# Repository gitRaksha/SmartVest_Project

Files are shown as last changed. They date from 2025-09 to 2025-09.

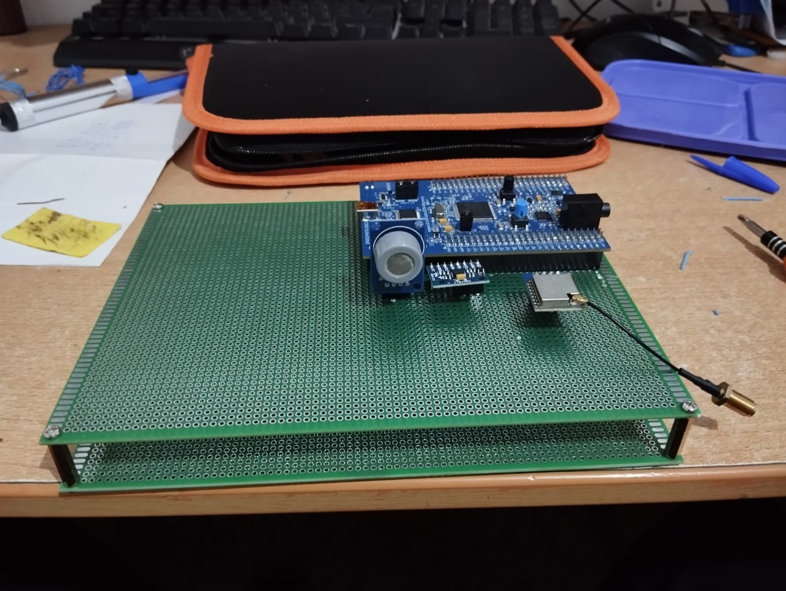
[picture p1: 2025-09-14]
Images/WhatsApp Image 2025-05-27 à 20.13.04_19ec891d.jpg

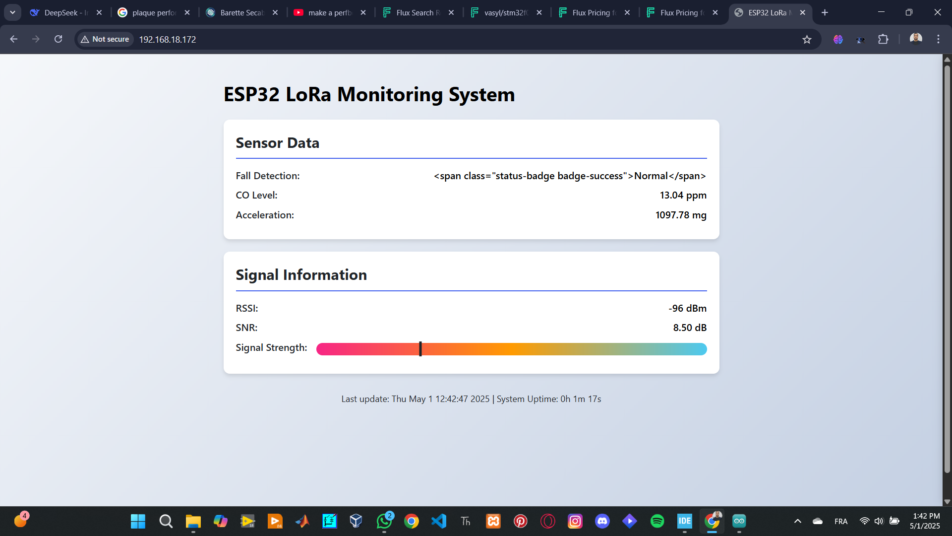
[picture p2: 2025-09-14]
Images/Capture d'écran 2025-05-01 134303.png

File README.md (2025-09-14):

       

# 🦺 Smart Safety Vest – IoT Project  

A **Smart Safety Vest** designed for workers in hazardous environments.  
It detects **toxic gas (CO)** and **falls**, then transmits alerts via **LoRa (SX1278)** from an **STM32F407G** to an **ESP32**, which hosts a **web dashboard** for monitoring.  

This project was developed as an **End-of-Year Engineering Project (PFA)**.  

---

## ✨ Features
- 📡 **LoRa Communication**: Long-range wireless transmission of alerts.  
- 🧭 **Fall Detection**: Using MPU6050 accelerometer.  
- 🌫 **Gas Detection**: CO levels via MQ-7 sensor.  
- 🌍 **Web Dashboard**: ESP32 receives LoRa data and displays it on a local web page.  
- 🔋 **Portable Design**: PCB + 3D printed case for deployment.  

---

## 🛠 Hardware Used
🔹 **STM32F407G** microcontroller (main vest controller)  
🔹 **ESP32** (LoRa receiver + Wi-Fi access point / web interface)  
🔹 **LoRa SX1278** transceiver modules (433 MHz)  
🔹 **MQ-7** gas sensor (CO detection)  
🔹 **MPU6050** accelerometer/gyroscope (fall detection)  
🔹 **Buzzer + LED indicators** (local alerts)  
🔹 **Li-Ion Battery 3.7V** + **TP4056 charger module**  
🔹 **Custom PCB** (Proteus/Altium design included)  
🔹 **3D Printed Enclosure** (OpenSCAD design provided)  

---

## 💻 Software & Tools
- 🖥️ **STM32CubeIDE** or **Keil uVision** (STM32 firmware)  
- 🖥️ **Arduino IDE** (ESP32 firmware)  
- 🖥️ **Proteus** / **Altium Designer** (PCB design)  
- 🖥️ **OpenSCAD** (3D case design)  
- 🖥️ **Node-RED (optional)** (IoT dashboards)  

---

## 📂 Project Structure

```text
.
├── 3D design OpenScad # Enclosure design (box + lid)
├── CODE # Source codes
│ ├── esp32_final # ESP32 receiver + web server
│ └── stm32_final_code # STM32 sensor reading + LoRa sender
├── Images # Screenshots, wiring photos, etc.
├── PCB # PCB design files (Altium + Proteus)
├── Rapport_PFA.pdf # Final written report
└── Vidéo.mp4 # Demo video of the project

 ```

---

## 🚀 Deployment  

### 🔹 STM32 (Sender – on the vest)  
1. Open `stm32_final_code` in **STM32CubeIDE**.  
2. Flash the firmware to your STM32F407G.  
3. Connect MQ-7 + MPU6050 + LoRa SX1278 as per schematic.  

### 🔹 ESP32 (Receiver – Web Dashboard)  
1. Open `esp32_final` in **Arduino IDE**.  
2. Install required libraries:  
   - `LoRa.h`  
   - `WiFi.h`  
   - `WebServer.h`  
3. Flash to ESP32.  
4. Connect ESP32 to LoRa SX1278.  
5. Open a browser and navigate to the ESP32 IP to view alerts.  

---

## 📸 Images & Demo
Some project visuals are stored in the [Images](./Images) folder.  
A demo video is available: [Vidéo.mp4](./Vidéo.mp4).  

---

## 🔮 Future Improvements

🌍 Add GPS for geolocation

📡 Add GSM/4G for connectivity without LoRa

🔋 Optimize power management

☁️ Cloud-based dashboard (IoT integration)

---

## 📜 License
This project is licensed under the **MIT License** – see the [LICENSE](./LICENSE) file for details.  

---

## 👥 Authors
- **Marwen Mekni** 
- **Bensaid Mohamed**
- **Khemiri Haythem** 

---

⭐ If you like this project, feel free to fork, star, or reuse it for your own IoT projects!

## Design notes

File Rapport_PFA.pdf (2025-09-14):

## Étude et conception d’un Gilet Intelligent pour Travailleurs en Milieu Dangereux avec Intégration de l’IoT

BENSAID Mohamed, MEKNI Marwen, KHEMIRI Haythem Mohamedbensaidtn@gmail.com, mekni0845@gmail.com, haythemkhmiri92@gmail.com

(1) L'Ecole Supérieure d'Ingénieurs et des Etudes Technologiques ESIET -UAS :34, Rue Cyrus Legrand, Tunis, Tunisie.
(2) L'Ecole Supérieure d'Ingénieurs et des Etudes Technologiques ESIET -UAS :34, Rue Cyrus Legrand, Tunis, Tunisie.
RESUME : Ce projet présente la conception et la réalisation d’un gilet intelligent destiné à renforcer la sécurité des travailleurs évoluant dans des environnements dangereux. L’objectif principal est de détecter les chutes et les gaz toxiques, notamment le monoxyde de carbone, le méthane et l’hydrogène, afin de déclencher des alertes en temps réel.
Le système est basé sur un microcontrôleur STM32F407G, relié à deux capteurs principaux : le MPU6050 pour la détection des chutes, et le capteur MQ-7 pour la surveillance des gaz. Les données collectées sont transmises via un module LoRa SX1278 vers un ESP32, qui les affiche sur une interface web hébergée localement.
L'ensemble du système fonctionne de manière autonome et sans réseau externe, ce qui le rend particulièrement adapté aux zones industrielles isolées. Le projet a été développé en suivant une approche modulaire, avec des tests individuels pour chaque composant, puis une intégration finale réussie. Il constitue une base solide pour des applications de sécurité connectée dans le domaine professionnel.
Mots-clés : Capteurs, Internet des Objets (IoT), Pédagogique, Sécurité au travail, Détection de chute, Capteur de gaz (MQ-7), STM32F407G, LoRa SX1278, ESP32, Interface web embarquée.

### 1. INTRODUCTION

Dans les environnements industriels et les chantiers à haut risque, la sécurité des travailleurs est une priorité absolue. Chaque année, des millions d'accidents surviennent, souvent causés par des chutes ou l’exposition à des gaz toxiques tels que le monoxyde de carbone (CO), le méthane (CH₄) ou l’hydrogène (H₂). Malgré les efforts en matière de prévention, ces dangers persistent, en particulier dans les zones peu surveillées. Face à ce constat, les objets connectés (IoT) offrent de nouvelles perspectives pour améliorer la sécurité en temps réel. Ce projet s'inscrit dans cette démarche, avec la conception d’un gilet intelligent capable de détecter les chutes et de surveiller la qualité de l’air, tout en transmettant les informations sans fil à une plateforme distante.
Le gilet se veut léger, autonome et adapté aux contraintes du terrain, intégrant des capteurs précis et une technologie de transmission à longue portée. Il vise à renforcer la protection des travailleurs en permettant une réaction rapide en cas d’anomalie détectée. Ce prototype démontre comment des solutions embarquées peuvent être mises au service de la sécurité dans des milieux exigeants.

### 2. CONCEPTION MECANIQUE

Pour la partie mécanique du projet, nous avons conçu un boîtier sur mesure à l’aide du logiciel OpenSCAD. Ce boîtier a été généré entièrement par code, ce qui a permis une modélisation paramétrique précise adaptée aux dimensions réelles des composants électroniques, notamment la carte

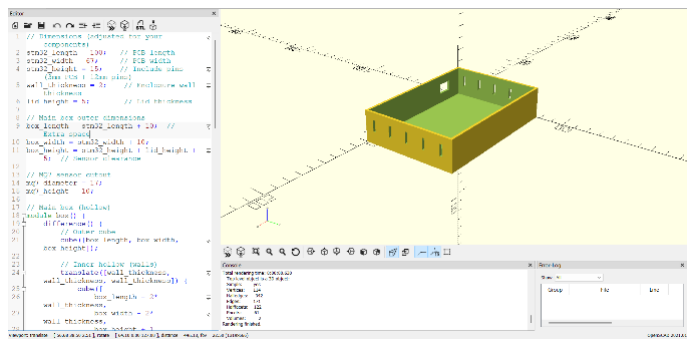
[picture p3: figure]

STM32F407G, le capteur MQ-7 et le module LoRa.

La structure comprend des parois d’épaisseur uniforme, un système de couvercle emboîtable, ainsi que des ouvertures dédiées pour le port USB, le capteur de gaz, l’antenne LoRa et la ventilation. Des fentes d’aération ont été ajoutées sur les côtés afin d’assurer une meilleure circulation de l’air à l’intérieur du boîtier.
Cette approche a permis une intégration compacte,
propre | et | fonctionnelle | de | l’ensemble | des
composants tout en assurant une certaine protection physique lors des tests. Le modèle final a été exporté en STL pour impression 3D si nécessaire.

Figure 1 : Conception 3D de boîtier

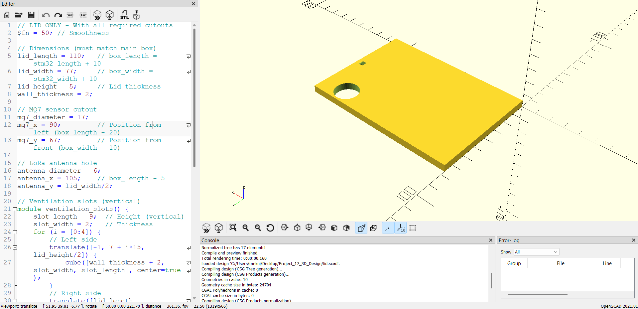
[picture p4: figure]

Figure 2 : Conception 3D du couvercle emboîtable

- Câblage électrique

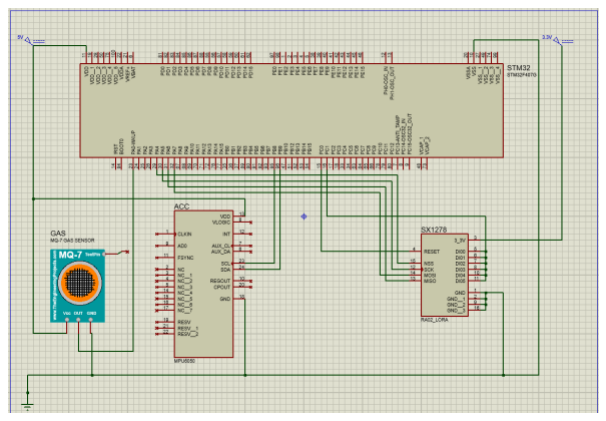
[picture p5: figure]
Figure 2 : Capteur de couleur TCS2300
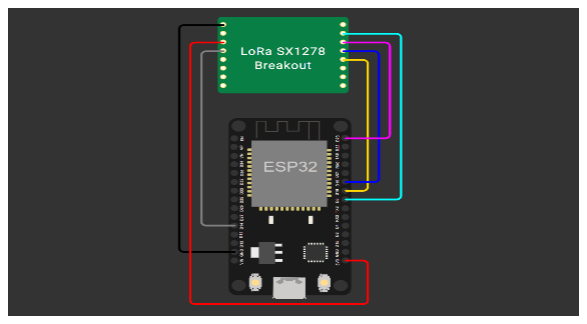
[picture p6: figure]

Figure 4 : Schéma électrique avec Proteus 8 de STM32 et ses capteurs

Le tableau suivant présente les connexions entre les broches des microcontrôleurs (STM32F407G et ESP32) et les différents modules utilisés dans le projet.

MPU6050 / STM32 | STM32/LORA | LORA/ESP32
VCC | 5V | VCC | 3, 3V | 3, 3V | 3, 3V
GND | GND | GND | GND | GND | GND
SDA | PB8 | PC0 | RST | RST | 19
SCL | PB9 | PC1 | DIO0 | DIO0 | 27
MQ7 /STM32 | | PA4 | NSS | NSS | 26
VCC | 5V | PA5 | SCK | SCK | 5
GND | GND | PA6 | MISO | MISO | 14
AO | PA0 | PA7 | MOSI | MOSI | 18

Tableau 1 : Table des connexions (Pinout)

### 3. ARCHITECTURE FONCTIONNEL

DU SYSTEME

Le projet ne comporte pas de parties mécaniques mobiles, donc aucun schéma cinématique n’est requis.
À la place, nous présentons ici l'architecture fonctionnelle du système qui repose sur un microcontrôleur STM32F407G connecté à deux capteurs : le MPU6050 en I2C pour détecter les chutes, et le MQ-7 en entrée analogique pour mesurer les gaz. Les données sont envoyées via le module LoRa SX1278 (SPI) à une carte ESP32, qui les affiche sur une interface web locale. Le schéma ci-dessous montre les connexions et le flux d’information entre les composants.

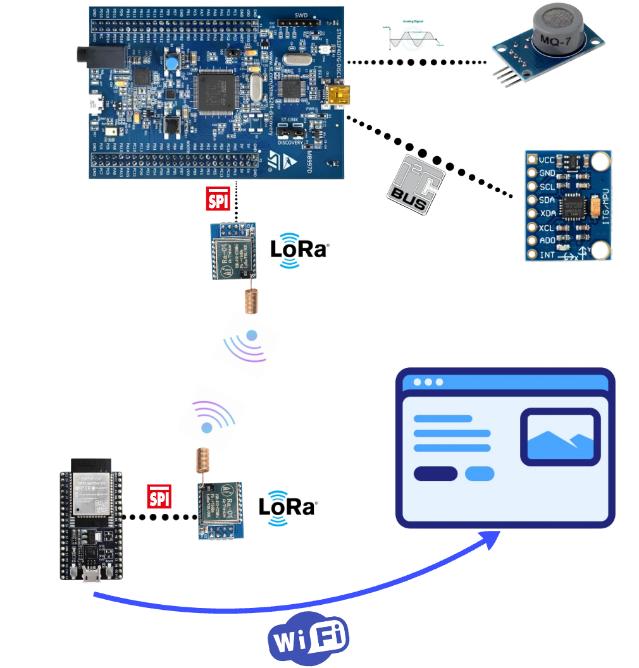
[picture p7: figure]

Figure 4 : Architecture globale du projet

### 4. CONSOMMATION ÉLECTRIQUE

Le système a été conçu pour consommer un
minimum | d’énergie | tout | en | assurant | un
fonctionnement continu. La carte STM32F407G consomme environ 50 à 100 mA en fonctionnement normal. Les capteurs MPU6050 et MQ-7 ajoutent une consommation faible, autour de 10 à 20 mA chacun. Le module LoRa SX1278, quant à lui, peut
consommer | jusqu’à | 120 mA | pendant | les
transmissions. L’ESP32 utilisé comme récepteur consomme entre 80 et 240 mA selon les phases d’activité.
L’ensemble du système fonctionne sous une tension de 3,3 V ou 5 V selon les composants. La
consommation | totale | reste | adaptée | à | une
alimentation portable, notamment par batterie rechargeable (entre 2000 et 3000mAh), pour une autonomie de plusieurs jours.

Figure 3 : Schéma électrique avec Proteus 8 de STM32 et ses capteurs

### 5. SÉCURITÉ ET ENVIRONNEMENT

D'UTILISATION DU GILET

### 5.1 Description :

Le gilet intelligent a été conçu pour renforcer la sécurité des travailleurs évoluant dans des environnements industriels à risque, tels que les usines, les chantiers, ou encore les zones confinées. Ces milieux sont souvent exposés à des dangers invisibles comme les gaz toxiques, ainsi qu’à des accidents liés aux déplacements ou aux pertes d’équilibre. Ce projet répond à ce besoin en intégrant des fonctionnalités de détection, d’alerte et de surveillance dans un système portable et autonome. Afin de garantir la robustesse et la fiabilité du dispositif
dans | son | environnement | d’utilisation, | plusieurs
précautions techniques ont été prises :
- Autonomie énergétique : le système est conçu d'être alimenté par une batterie portable connectée directement à la carte STM32F407G. Cette carte alimente également les autres composants via ses sorties 3.3 V et 5 V, ce qui permet un fonctionnement sans dépendance à un ordinateur ou à une source d’alimentation externe fixe. L’ensemble a été optimisé pour fonctionner en continu pendant plusieurs Jours.
- Protection mécanique des composants : les éléments électroniques sont intégrés dans un boîtier sur mesure, modélisé avec le logiciel OpenSCAD. Ce boîtier, conçu par génération de code, dispose d’un couvercle emboîtable, de fentes de ventilation latérales, ainsi que de découpes précises pour le capteur MQ-7, le port USB, et l’antenne LoRa. Il a été pensé pour protéger le système des chocs légers, de la poussière et de la chaleur.
- Fonctionnement sans infrastructure réseau : grâce à l’utilisation de la technologie LoRa, le gilet peut transmettre les données à longue distance, sans avoir besoin de connexion Wi-Fi ou GSM. Cela rend le
système | particulièrement | adapté | à | des
environnements industriels éloignés ou mal couverts.
- Ergonomie et intégration : le gilet a été pensé pour être confortable à porter, tout en assurant une bonne fixation des capteurs. L’assemblage des composants et des fils a été organisé de manière à limiter l’encombrement et à garantir une bonne stabilité du système lors des mouvements de l’utilisateur.
- Visualisation des données à distance : les informations sont envoyées à un module ESP32, qui héberge une page web locale affichant en temps réel les alertes ou mesures collectées. Cela permet à un responsable de surveiller les conditions de sécurité sans avoir à s’approcher physiquement du porteur du gilet.

En résumé, le gilet est conçu comme un dispositif de sécurité proactive, capable de fonctionner dans des conditions réelles de travail, avec une attention particulière portée à la fiabilité, la simplicité d’usage, et l’intégration dans l’environnement industriel. Son architecture technique et sa structure physique font de lui un prototype solide, réplicable et prometteur pour des applications futures en sécurité connectée.

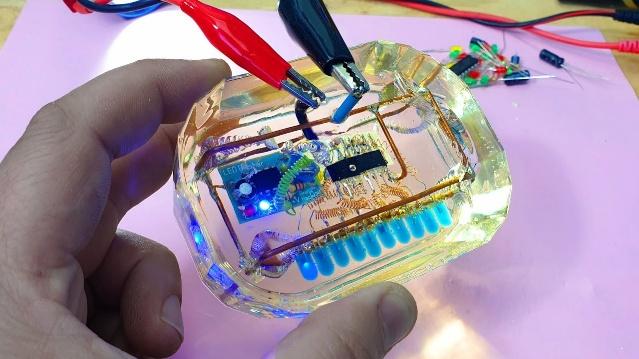
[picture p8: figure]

Figure 5 : Exemple d’utilisation de résine pour la protection mécanique d’un circuit électronique

### 6. CONTROL D'ACCES AUX DONNES

Dans notre système, la question du contrôle d’accès ne concerne pas une ouverture physique, mais plutôt l’accès aux données de sécurité transmises par le gilet. Les informations collectées (alertes de chute, détection de gaz) sont affichées sur une interface web hébergée localement par l’ESP32.
Cette interface est accessible uniquement via le réseau local, ce qui limite l’exposition extérieure et renforce la sécurité des données. L’accès à l’interface peut être restreint en configurant le réseau Wi-Fi ou en ajoutant un mot de passe au niveau du serveur web. Cela permet d’assurer que seules les personnes autorisées (responsables sécurité, chefs d’équipe...) puissent consulter les informations en temps réel.

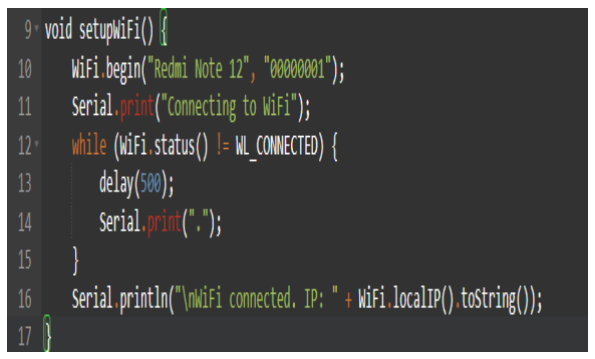
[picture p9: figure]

Figure 6 : Partie de code illustrant le setup de réseau local sécurisé

### 7. INTÈGRATION DE l’IOT

### 7.1 Communication par LoRa

L’intégration de l’IoT dans notre projet repose sur la transmission sans fil des données de sécurité depuis le gilet vers une plateforme de visualisation distante. Pour cela, nous avons adopté la technologie LoRa (Long Range), qui se distingue par sa capacité à transmettre des données sur de longues distances avec une très faible consommation d’énergie, ce qui la rend particulièrement adaptée aux applications industrielles, agricoles ou en milieux isolés.
LoRa est une technologie de modulation radio basée sur le spectre étalé à modulation chirp (Chirp Spread Spectrum - CSS), développée pour assurer des
communications | robustes | même | dans | des
environnements bruyants ou à faible puissance. Elle fonctionne dans des bandes de fréquences non licenciées (souvent autour de 433 MHz ou 868 MHz en Europe) et permet des portées de transmission allant de 2 à 15 kilomètres en champ libre, selon les antennes et les conditions environnementales.
Contrairement aux protocoles classiques comme le Wi-Fi ou le Bluetooth, qui nécessitent une infrastructure de réseau (routeur, passerelle, etc.), LoRa permet une communication directe entre deux nœuds : un émetteur et un récepteur. Cela élimine la dépendance à Internet ou à un réseau local et renforce la fiabilité dans les zones à faible connectivité.
Dans notre projet, la carte STM32F407G joue le rôle d’unité centrale embarquée dans le gilet. Elle récupère en temps réel les données des capteurs :
- MPU6050 pour la détection des chutes, via le bus I²C,
- MQ-7 pour la mesure du monoxyde de carbone, via une entrée analogique.

Ces informations sont ensuite formatées et transmises par le module LoRa SX1278, connecté au STM32 via une interface SPI. La transmission est reçue par une carte ESP32, qui agit comme une station de réception. L’ESP32 décode les données reçues et les affiche sur une interface web hébergée localement, accessible depuis un ordinateur, une tablette ou un smartphone connecté au même réseau local que l’ESP32.
Ce mode de communication point-à-point garantit :
- Une grande autonomie du système (grâce à la faible consommation du module LoRa),
- Une portée étendue,
- | Une | simplicité | de | déploiement, | sans
infrastructure lourde.

L’utilisation de LoRa renforce ainsi la robustesse et la portabilité du gilet intelligent, tout en assurant une transmission fiable des données critiques dans des environnements de travail potentiellement dangereux.

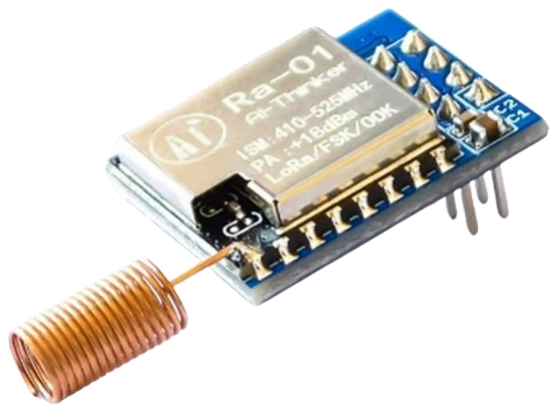
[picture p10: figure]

Figure 7 : Module LoRa utilisé "SX 1278 RA-01" avec la bande de fréquence 433MHz

### 7.2 Affichage des données et surveillance en

temps réel

Une interface web simple et intuitive a été développée sur l’ESP32 afin de présenter les données reçues. Elle permet d’afficher en temps réel les alertes, les valeurs des capteurs et l’état général du système. L’interface fonctionne sans connexion Internet et peut être consultée sur smartphone, tablette ou PC.
Cette intégration permet :
- | Une | surveillance | continue | sans
infrastructure externe,
- Une réduction des coûts liés aux plateformes cloud,
- Et une meilleure réactivité en cas de
| danger.
Des améliorations futures pourraient inclure l'ajout d'un module Wi-Fi pour synchroniser les données avec une plateforme cloud ou déclencher des notifications automatiques en cas de détection critique.

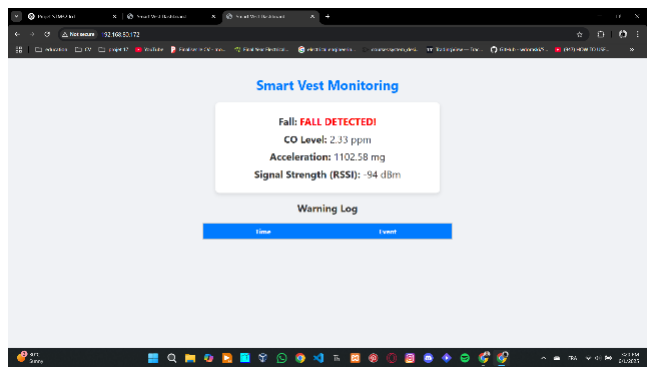
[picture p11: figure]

Figure 8 : Interface web embarquée sur l'ESP32 affichant les données en temps réel

### 8. SCHEMA DE CONCEPTION

ELECTRONIQUE ET PRESPECTIVES D'INTEGRATION MATRIELLE

Dans le cadre de l’étude matérielle du projet, nous avons réalisé les schémas électroniques des principaux composants du système à l’aide du logiciel Altium Designer. Ces schémas incluent le capteur MPU6050 (I²C), le capteur de gaz MQ-7 (analogique), et le module LoRa SX1278 (SPI), chacun étant connecté à un microcontrôleur STM32.
Cette étape de conception a permis de mieux comprendre les exigences électriques de chaque composant et leur interconnexion. Elle constitue également une base solide pour une évolution future du projet : le développement d’un circuit imprimé (PCB) personnalisé.
Une telle carte pourrait regrouper tous les éléments du gilet intelligent sur un seul support : le microcontrôleur STM32 (sous forme de puce), les capteurs, le module LoRa, ainsi que les composants passifs (résistances, condensateurs) et les régulateurs de tension nécessaires. Ce type d’intégration matérielle offrirait de nombreux avantages :
- Une réduction de la taille et du poids du dispositif ;
- Une meilleure robustesse mécanique et électrique ;
- Une fabrication industrielle facilitée ;
- Et une optimisation de la consommation énergétique.

Cette approche représente une évolution naturelle vers un produit fini prêt à être testé sur le terrain ou industrialisé.

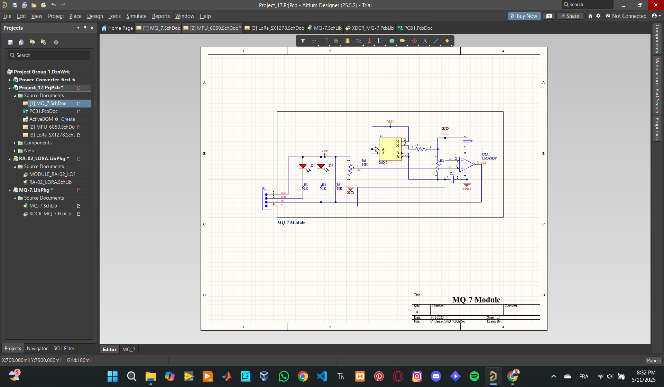
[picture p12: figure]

Figure 9 : Vue de l’interface du logiciel Altium Designer utilisé pour la conception des schémas électroniques.

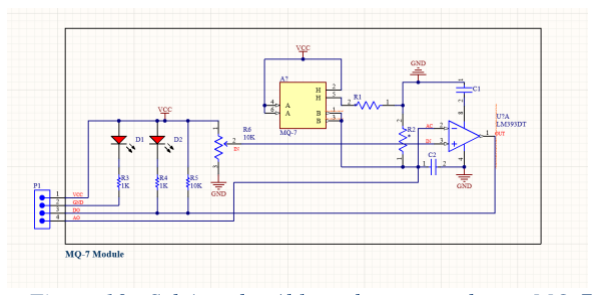
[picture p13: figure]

Figure 10 : Schéma de câblage du capteur de gaz MQ-7 réalisé sur Altium.

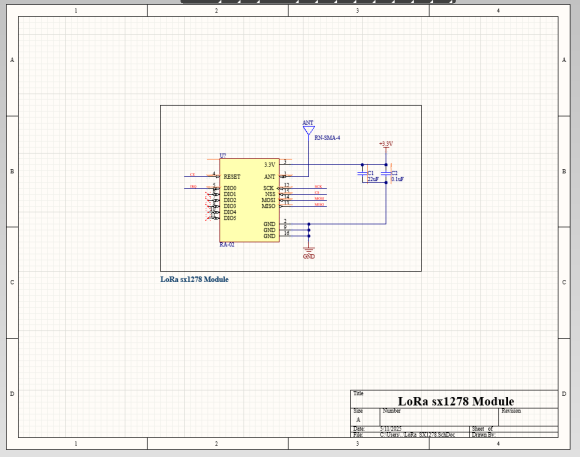
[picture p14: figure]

Figure 11 : Schéma du module LoRa SX1278 avec son interface SPI et les broches de contrôle.

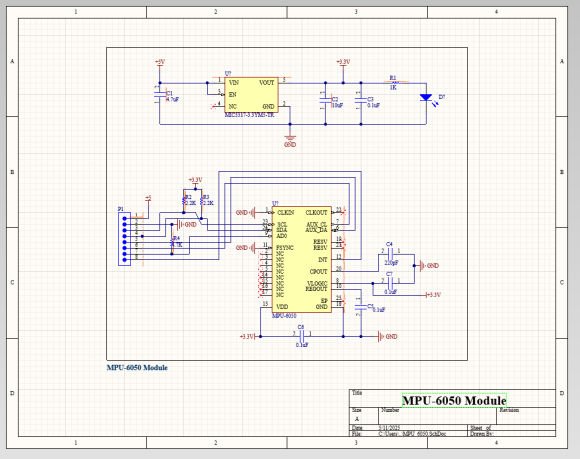
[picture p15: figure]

Figure 12 : Schéma de connexion du capteur MPU6050 (accéléromètre/gyroscope) sur Altium Designer.

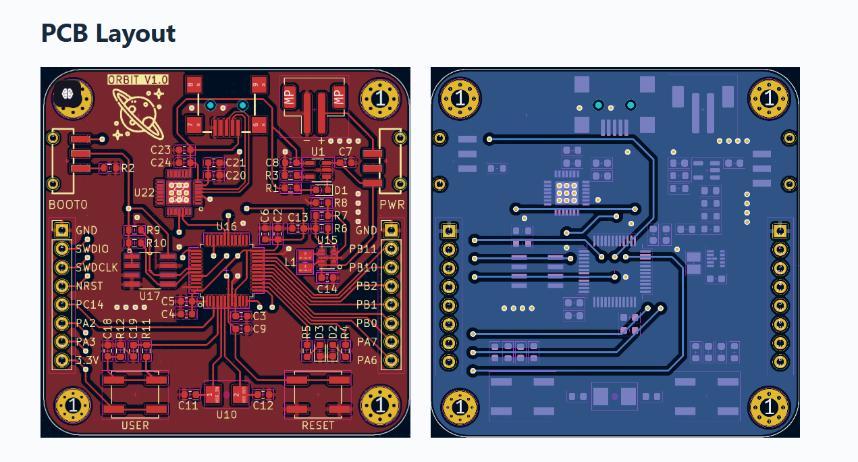
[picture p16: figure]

Figure 13 : Exemple d'une PCB complète

### 9. RÈALISATION

Après avoir mené à bien l'étude approfondie du projet, il est désormais temps de passer à la phase de réalisation. Afin d'assurer une mise en œuvre efficace, nous avons soigneusement sélectionné et acquis les matériaux indispensables, tels que les capteurs, les fils
de | connexion, | les | vis | et | les | écrous. Cette
étape inaugure le | début | de | l'assemblage | et | de
l'intégration des composants, tout en veillant à optimiser la qualité et la fiabilité du système.

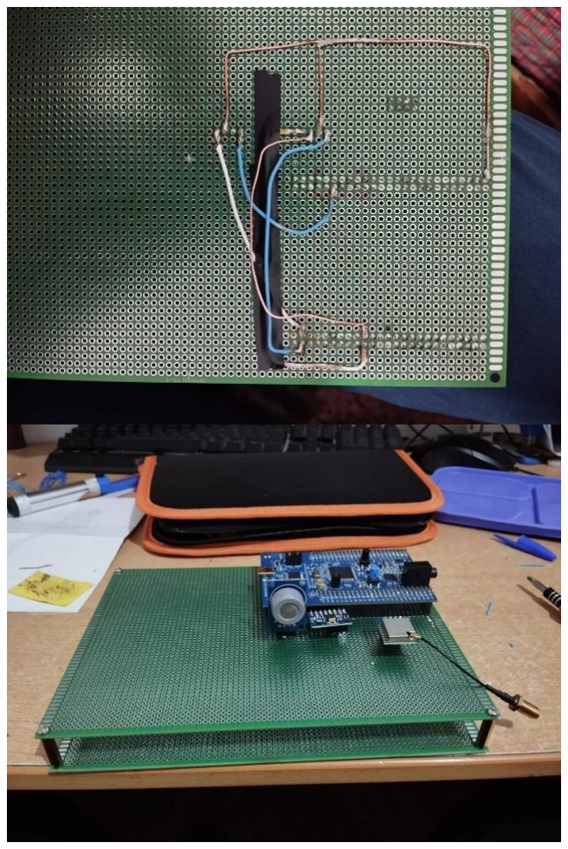
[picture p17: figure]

Figure 14 : Maquette en cours de réalisation

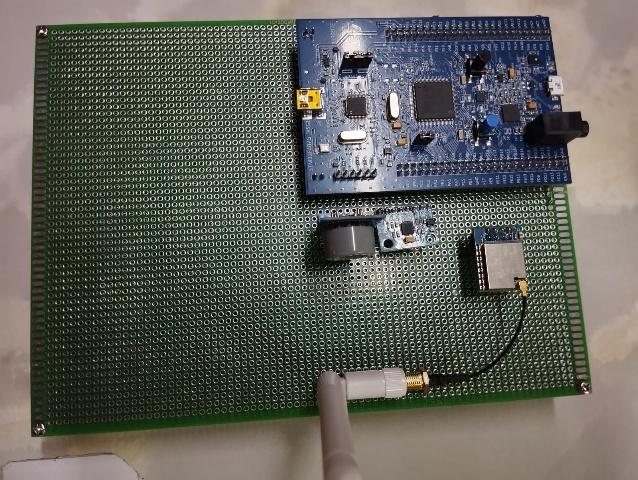
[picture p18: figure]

Figure 15 : Maquette réalisé produit final

### 10. PERSPECTIVES

Le projet du gilet intelligent peut évoluer vers une version plus complète et adaptée aux contraintes réelles du terrain. Plusieurs pistes d’amélioration sont envisageables pour renforcer ses fonctionnalités et son autonomie.

- L’intégration d’une batterie de plus grande capacité ou d’un système de recharge solaire permettrait d’étendre l’autonomie du dispositif pour une utilisation sur de longues périodes, sans dépendance à une source externe.
- De nouveaux capteurs pourraient être ajoutés, tels qu’un module GPS pour localiser précisément l’utilisateur, ou des capteurs de température, de pression atmosphérique, voire d’humidité, afin de compléter les données environnementales.
- Le développement d’un système d’enregistrement des événements (détections de chutes, niveaux de gaz, alertes) permettrait de conserver un historique consultable à travers une base de données locale ou distante, éventuellement accessible via un tableau de bord complet.
- Il serait également envisageable de miniaturiser le dispositif en concevant une carte électronique dédiée (PCB) intégrant tous les composants, ce qui faciliterait la production, la fiabilité et le port à long terme.
- Enfin, l’ajout d’un système de notifications en temps réel (par e-mail, SMS ou application mobile) permettrait d’alerter instantanément les responsables de sécurité en cas de détection critique, même à distance.

Ces évolutions rendraient le gilet plus performant, plus autonome, et plus proche d’un produit commercialisable, prêt à être déployé dans un environnement professionnel réel.

### 11. CONCLUSION

Ce projet de gilet intelligent pour travailleurs en milieu dangereux réunit plusieurs technologies clés, notamment l’électronique embarquée, les capteurs environnementaux, les communications sans fil avec la technologie LoRa, ainsi que le développement d’une interface web locale via l’ESP32. Il constitue une maquette fonctionnelle et éducative destinée à sensibiliser les futurs ingénieurs de l’ESIET-UAS à l’importance de la sécurité connectée dans les environnements industriels.

Ce projet illustre également l’intégration efficace de solutions IoT autonomes, sans dépendance à une infrastructure réseau, tout en offrant une surveillance en temps réel des conditions de travail. Dans un contexte professionnel, un tel dispositif pourrait être adapté à divers secteurs comme les chantiers, les zones confinées ou les industries chimiques, afin de prévenir les accidents et améliorer la réactivité en cas de danger.

Son potentiel d’évolution vers une version portable, connectée à une base de données ou intégrée à un tableau de bord complet, ouvre la voie à une future industrialisation et à une meilleure prise en charge de la sécurité des opérateurs sur le terrain.

Bibliographie

[1]. M STMicroelectronics. STM32F407xx Datasheet.
[En | ligne]. | Disponible | sur | :
https://www.st.com/resource/en/datasheet/stm32f4 07vg.pdf (https://www.st.com/resource/en/datasheet/stm32f407vg.pdf)
[2]. Seeed Studio. MQ-7 Gas Sensor Datasheet. [En ligne]. Disponible sur :
https://files.seeedstudio.com/wiki/Grove-Gas_Sensor-MQ7/res/MQ-7.pdf (https://files.seeedstudio.com/wiki/Grove-Gas_Sensor-MQ7/res/MQ-7.pdf)
[3]. InvenSense. MPU-6050 Register Map and Datasheet. [En ligne]. Disponible sur : https://invensense.tdk.com/wpcontent/uploads/2015/02/MPU-6000-Register-Map1.pdf (https://invensense.tdk.com/wp-content/uploads/2015/02/MPU-6000-Register-Map1.pdf)
[4]. Semtech. SX1278 LoRa Transceiver Datasheet. [En ligne]. Disponible sur : https://www.semtech.com/uploads/documents/sx1276_77_78_79.pdf (https://www.semtech.com/uploads/documents/sx1276_77_78_79.pdf)
[5]. STMicroelectronics. STM32CubeIDE – Integrated Development Environment. [En ligne]. Disponible sur :
https://www.st.com/en/developmenttools/stm32cubeide.html (https://www.st.com/en/development-tools/stm32cubeide.html)
[6]. OpenSCAD. The Programmers Solid 3D CAD Modeller. [En ligne]. Disponible sur : https://openscad.org/
[7]. Wokwi. Online IoT and Arduino Simulator. [En ligne]. Disponible sur : https://wokwi.com/

[8]. Proteus Design Suite. Simulation et conception de circuits électroniques. [En ligne]. Disponible sur :
https://www.labcenter.com/
[9]. Altium. Altium Designer – PCB Design Software. [En ligne]. Disponible sur : https://www.altium.com/altium-designer/[10]. Build a Battery Powered STM32 Board:
https://embeddedprojects101.com/designa-battery-powered-stm32-board-withusb/#AT24C128_EEPROM (https://embeddedprojects101.com/design-a-battery-powered-stm32-board-with-usb/%23AT24C128_EEPROM)

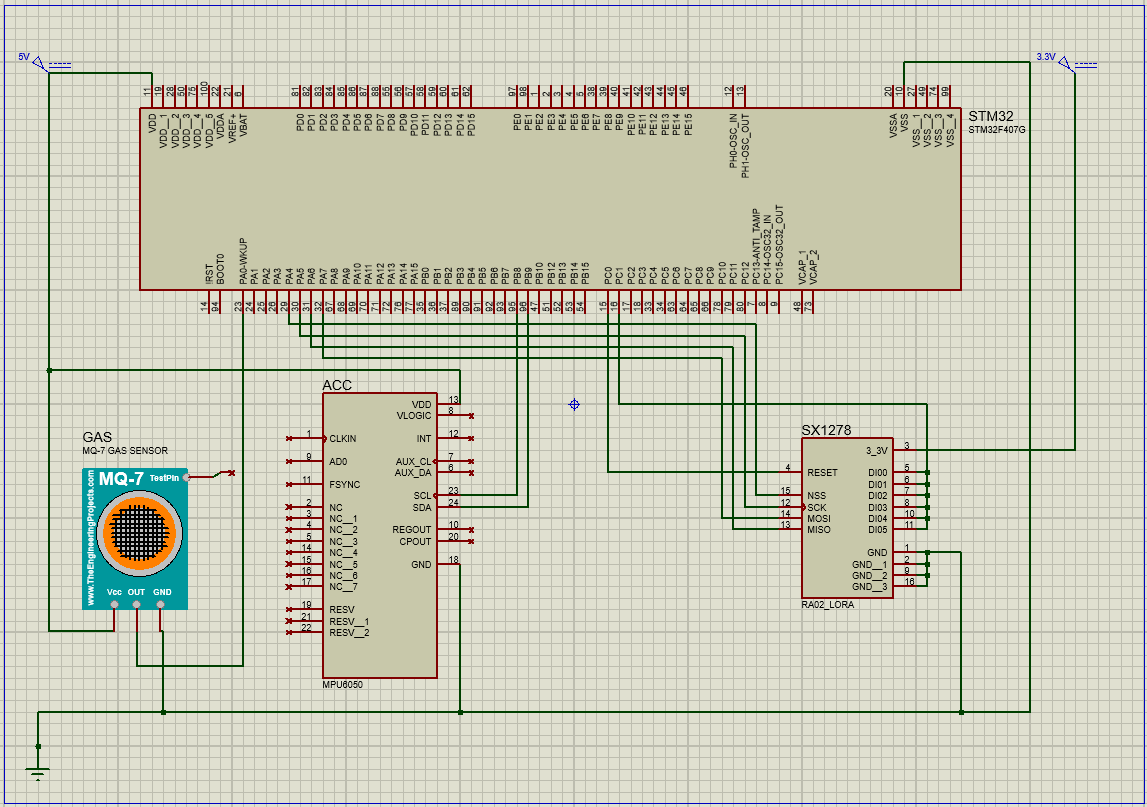
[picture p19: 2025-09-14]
Images/Capture d'écran 2025-06-03 123803.png

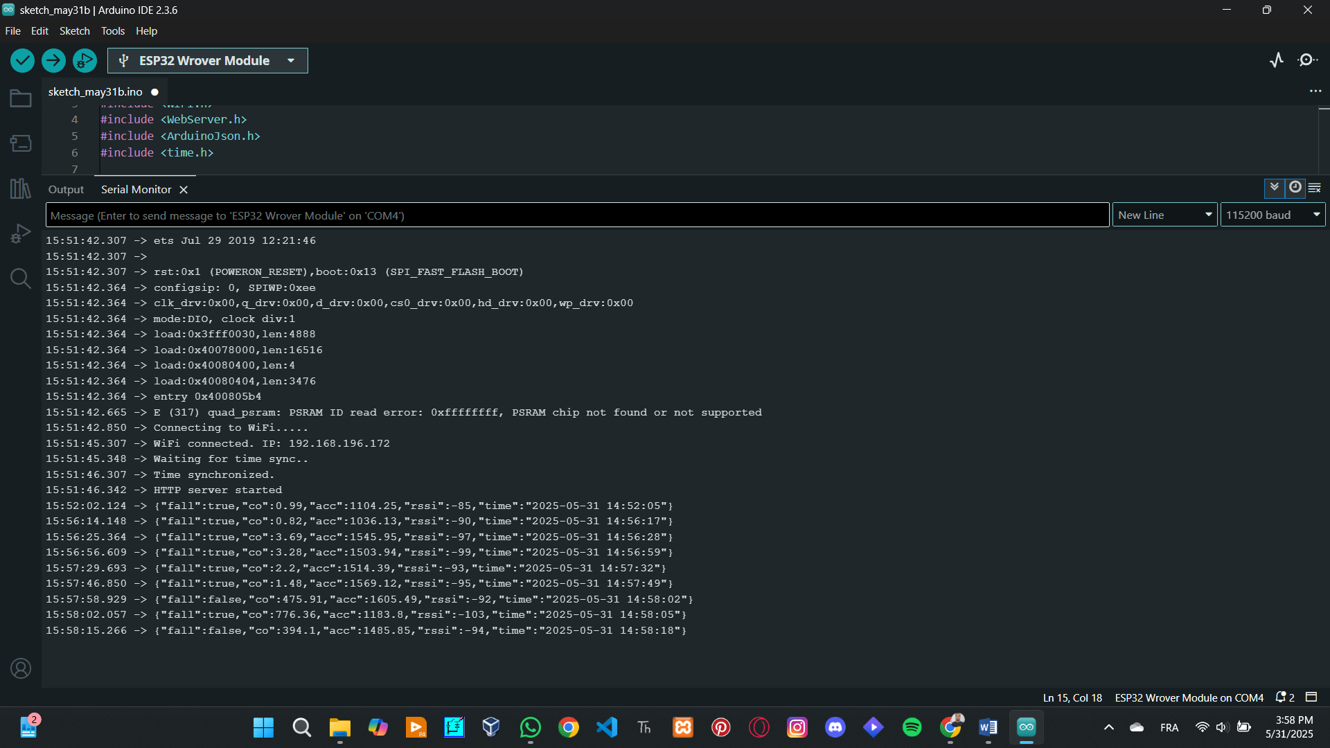
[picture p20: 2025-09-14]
Images/Capture d'écran 2025-05-31 155849.png

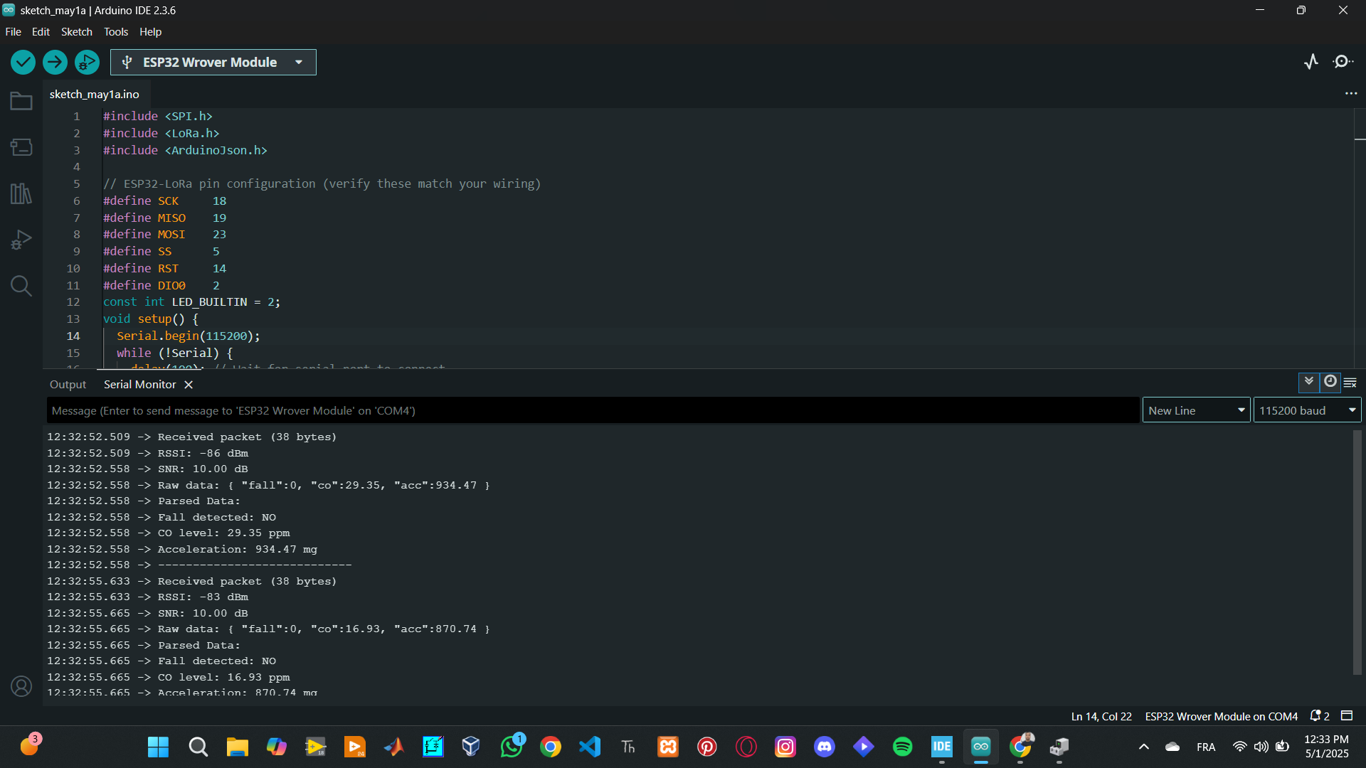
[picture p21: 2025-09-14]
Images/Capture d'écran 2025-05-01 123348.png

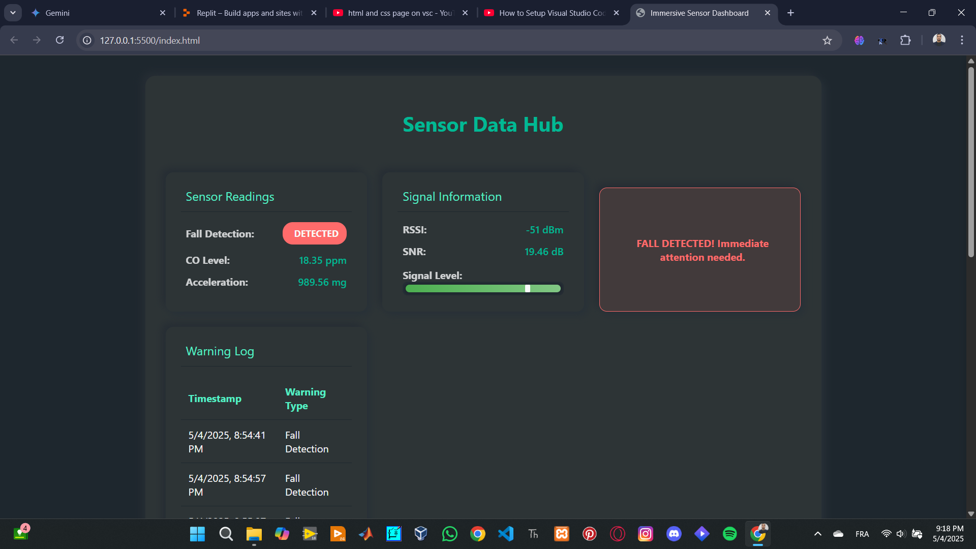
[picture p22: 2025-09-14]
Images/Capture d'écran 2025-05-04 211834.png

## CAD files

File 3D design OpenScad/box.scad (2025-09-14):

// Dimensions (adjusted for your components)
stm32_length = 100;   // PCB length
stm32_width = 67;     // PCB width
stm32_height = 15;    // Include pins (3mm PCB + 12mm pins)
wall_thickness = 2;    // Enclosure wall thickness
lid_height = 5;        // Lid thickness

// Main box outer dimensions
box_length = stm32_length + 10;  // Extra space
box_width = stm32_width + 10;    
box_height = stm32_height + lid_height + 5;  // Sensor clearance

// MQ7 sensor cutout
mq7_diameter = 17;  
mq7_height = 10;     

// Main box (hollow)
module box() {
    difference() {
        // Outer cube
        cube([box_length, box_width, box_height]);
        
        // Inner hollow (walls)
        translate([wall_thickness, wall_thickness, wall_thickness]) {
            cube([
                box_length - 2*wall_thickness,
                box_width - 2*wall_thickness,
                box_height + 1
            ]);
        }
        
        // Component holes
        holes();
    }
}

// Lid (snap-fit)
module lid() {
    difference() {
        cube([box_length, box_width, lid_height]);
        // Lip for fitting
        translate([wall_thickness, wall_thickness, -1]) {
            cube([
                box_length - 2*wall_thickness,
                box_width - 2*wall_thickness,
                lid_height + 2
            ]);
        }
    }
}

// Holes for components
module holes() {
    // LoRa antenna hole (side)
    translate([box_length - 5, box_width/2, box_height - 10]) {
        rotate([90, 0, 0]) {
            cylinder(h=wall_thickness + 2, d=6, center=true);
        }
    }
    
    // USB port hole (front)
    translate([15, -1, 10]) {
        cube([12, wall_thickness + 2, 8]);
    }
    
    // MQ7 sensor hole (top, circular)
    translate([box_length - 20, box_width - 10, box_height - mq7_height - 1]) {
        cylinder(h=mq7_height + 2, d=mq7_diameter);
    }
    
    // Slotted side vents (elongated)
    for (i = [0:4]) {
        // Left side
        translate([-1, 7 + i*15, box_height - 15]) {
            cube([wall_thickness + 2, 2, 9]);  // 10mm long, 3mm tall
        }
        // Right side
        translate([box_length - wall_thickness - 1, 7 + i*15, box_height - 15]) {
            cube([wall_thickness + 2, 2, 9]);
        }
    }
}

// Render box + lid (closed)
difference() {
    union() {
        box();
        translate([0, 0, box_height - lid_height]) lid();  // Lid in place
    }
    // Uncomment to debug cuts:
    // #holes();
}

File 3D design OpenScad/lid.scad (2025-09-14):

// LID ONLY - With all required cutouts
$fn = 50; // Smoothness

// Dimensions (must match main box)
lid_length = 110;   // box_length = stm32_length + 10
lid_width = 77;     // box_width = stm32_width + 10
lid_height = 5;     // Lid thickness
wall_thickness = 2; 

// MQ7 sensor cutout
mq7_diameter = 17;  
mq7_x = 90;         // Position from left (box_length - 20)
mq7_y = 67;         // Position from front (box_width - 10)

// LoRa antenna hole
antenna_diameter = 6;
antenna_x = 105;    // box_length - 5
antenna_y = lid_width/2;

// Ventilation slots (vertical)
module ventilation_slots() {
    slot_length = 9;  // Height (vertical)
    slot_width = 2;   // Thickness
    for (i = [0:4]) {
        // Left side
        translate([-1, 7 + i*15, lid_height/2]) {
            cube([wall_thickness + 2, slot_width, slot_length], center=true);
        }
        // Right side
        translate([lid_length - wall_thickness - 1, 7 + i*15, lid_height/2]) {
            cube([wall_thickness + 2, slot_width, slot_length], center=true);
        }
    }
}

// Main lid with holes
difference() {
    // Base lid
    cube([lid_length, lid_width, lid_height]);
    
    // MQ7 sensor hole (top)
    translate([mq7_x, mq7_y, -1]) {
        cylinder(h=lid_height + 2, d=mq7_diameter);
    }
    
    // LoRa antenna hole (side)
    translate([antenna_x, antenna_y, lid_height/2]) {
        rotate([90, 0, 0]) {
            cylinder(h=wall_thickness + 2, d=antenna_diameter, center=true);
        }
    }
    
  
}

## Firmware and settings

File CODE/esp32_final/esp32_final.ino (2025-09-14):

#include <SPI.h>
#include <LoRa.h>
#include <WiFi.h>
#include <WebServer.h>
#include <ArduinoJson.h>
#include <time.h>

String fallLog = "";  // ✅ Add this to declare the log variable

// Replace with your WiFi credentials
const char* ssid = "Redmi Note 12";         // <-- Change this
const char* password = "00000001"; // <-- Change this

// ======== LoRa Pins ========
#define SCK     5
#define MISO    19
#define MOSI    27
#define SS      18
#define RST     14
#define DIO0    26
#define LED_BUILTIN 2

WebServer server(80);

String latestData = "{}";
String warningLog = "";

void setupWiFi() {
  WiFi.begin(ssid, password);
  Serial.print("Connecting to WiFi");
  while (WiFi.status() != WL_CONNECTED) {
    delay(500);
    Serial.print(".");
  }
  Serial.println("\nWiFi connected. IP: " + WiFi.localIP().toString());
}

void setupTime() {
  configTime(0, 0, "pool.ntp.org", "time.nist.gov");
  Serial.print("Waiting for time sync");
  while (time(nullptr) < 100000) {
    delay(500);
    Serial.print(".");
  }
  Serial.println("\nTime synchronized.");
}

String getTimestamp() {
  time_t now = time(nullptr);
  struct tm* timeinfo = localtime(&now);
  char buffer[30];
  strftime(buffer, sizeof(buffer), "%Y-%m-%d %H:%M:%S", timeinfo);
  return String(buffer);
}
void setupWebServer() {
  server.on("/", HTTP_GET, []() {
    server.send(200, "text/html", generateHTML());
  });

  server.on("/data", HTTP_GET, []() {
    server.send(200, "application/json", latestData);
  });

  server.on("/log", HTTP_GET, []() {
    server.send(200, "text/plain", warningLog);
  });

  server.begin();
  Serial.println("HTTP server started");
}


void setup() {
  Serial.begin(115200);
  while (!Serial) delay(100);

  pinMode(LED_BUILTIN, OUTPUT);
  setupWiFi();
  setupTime();

  SPI.begin(SCK, MISO, MOSI, SS);
  LoRa.setPins(SS, RST, DIO0);
  if (!LoRa.begin(433E6)) {
    Serial.println("LoRa init failed.");
    while (true) delay(1000);
  }

  LoRa.setSpreadingFactor(7);
  LoRa.setSignalBandwidth(125E3);
  LoRa.setCodingRate4(5);
  LoRa.setPreambleLength(9);
  LoRa.setSyncWord(0x34);

  setupWebServer();
}

void loop() {
  server.handleClient();

  int packetSize = LoRa.parsePacket();
  if (packetSize) {
    String receivedData;
    while (LoRa.available()) {
      receivedData += (char)LoRa.read();
    }

    DynamicJsonDocument doc(256);
    if (deserializeJson(doc, receivedData) == DeserializationError::Ok) {
      bool fall = doc["fall"];
      float co = doc["co"];
      float acc = doc["acc"];
      int rssi = LoRa.packetRssi();

      DynamicJsonDocument jsonOut(256);
      jsonOut["fall"] = fall;
      jsonOut["co"] = co;
      jsonOut["acc"] = acc;
      jsonOut["rssi"] = rssi;
      jsonOut["time"] = getTimestamp();
      serializeJson(jsonOut, latestData);

      if (fall) {
  // Generate timestamp
  unsigned long seconds = millis() / 1000;
  unsigned long mins = seconds / 60;
  unsigned long hrs = mins / 60;

  String timeStamp = "[" + String(hrs % 24) + ":" + String(mins % 60) + ":" + String(seconds % 60) + "]";

  // Add fall log entry to HTML
  fallLog += "<tr><td>" + timeStamp + "</td><td>Fall detected!</td></tr>";
}



      Serial.println(latestData);
    }
  }

  static unsigned long lastBlink = 0;
  if (millis() - lastBlink > 1000) {
    lastBlink = millis();
    digitalWrite(LED_BUILTIN, !digitalRead(LED_BUILTIN));
  }
}
String generateHTML() {
  String html = R"rawliteral(
  <!DOCTYPE html>
  <html>
  <head>
    <meta charset="UTF-8">
    <meta name="viewport" content="width=device-width, initial-scale=1">
    <title>Smart Vest Dashboard</title>
    <style>
      body {
        font-family: 'Segoe UI', Tahoma, Geneva, Verdana, sans-serif;
        background-color: #f0f2f5;
        color: #333;
        text-align: center;
        margin: 0;
        padding: 20px;
      }
      h1 {
        color: #007BFF;
      }
      .card {
        background-color: white;
        border-radius: 10px;
        box-shadow: 0 4px 8px rgba(0,0,0,0.1);
        padding: 20px;
        margin: 20px auto;
        max-width: 500px;
      }
      .data {
        font-size: 1.5em;
        margin: 10px 0;
      }
      #fall {
        font-weight: bold;
      }
      table {
        margin: 20px auto;
        border-collapse: collapse;
        width: 90%;
        max-width: 600px;
      }
      th, td {
        border: 1px solid #ccc;
        padding: 8px 12px;
        text-align: center;
      }
      th {
        background-color: #007BFF;
        color: white;
      }
      tr:nth-child(even) {
        background-color: #f9f9f9;
      }
    </style>
  </head>
  <body>
    <h1>Smart Vest Monitoring</h1>

    <div class="card">
      <div class="data"><strong>Fall:</strong> <span id="fall">Loading...</span></div>
      <div class="data"><strong>CO Level:</strong> <span id="co">Loading...</span></div>
      <div class="data"><strong>Acceleration:</strong> <span id="acc">Loading...</span></div>
      <div class="data"><strong>Signal Strength (RSSI):</strong> <span id="rssi">Loading...</span></div>
    </div>

    <h2>Warning Log</h2>
    <table id="logTable">
      <tr><th>Time</th><th>Event</th></tr>
    </table>

    <script>
      function updateDashboard() {
        fetch('/data')
          .then(res => res.json())
          .then(data => {
            document.getElementById('fall').textContent = data.fall ? "FALL DETECTED!" : "No fall";
            document.getElementById('fall').style.color = data.fall ? "red" : "lime";
            document.getElementById('co').textContent = data.co + " ppm";
            document.getElementById('acc').textContent = data.acc + " mg";
            document.getElementById('rssi').textContent = data.rssi + " dBm";
          });

        fetch('/log')
          .then(res => res.text())
          .then(rows => {
            document.getElementById('logTable').innerHTML = "<tr><th>Time</th><th>Event</th></tr>" + rows;
          });
      }

      setInterval(updateDashboard, 2000);
      window.onload = updateDashboard;
    </script>
  </body>
  </html>
  )rawliteral";
  return html;
}

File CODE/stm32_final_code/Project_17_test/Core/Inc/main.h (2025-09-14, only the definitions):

#define RST_Pin GPIO_PIN_0
#define RST_GPIO_Port GPIOC
#define DIO0_Pin GPIO_PIN_1
#define DIO0_GPIO_Port GPIOC
#define NSS_Pin GPIO_PIN_4
#define NSS_GPIO_Port GPIOA
#define LED_MPU_Pin GPIO_PIN_12
#define LED_MPU_GPIO_Port GPIOD
#define LED_MQ7_Pin GPIO_PIN_13
#define LED_MQ7_GPIO_Port GPIOD
#define MPU_SCL_Pin GPIO_PIN_8
#define MPU_SCL_GPIO_Port GPIOB
#define MPU_SDA_Pin GPIO_PIN_9
#define MPU_SDA_GPIO_Port GPIOB

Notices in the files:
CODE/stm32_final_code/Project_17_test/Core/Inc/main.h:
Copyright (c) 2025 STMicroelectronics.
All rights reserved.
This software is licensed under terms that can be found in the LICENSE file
